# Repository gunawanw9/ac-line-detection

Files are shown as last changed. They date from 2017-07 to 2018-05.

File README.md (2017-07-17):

# [AC mains/ Zero Crossing Detection Module](https://shop.edwinrobotics.com/sensors/960-ac-mains-zero-crossing-detection-module.html) #

AC Mains Zero Crossing Detection PCB.JPG

The AC mains/ Zero Crossing Detection Module from Edwin Robotics is an optically isolated AC line-to-logic interface device. The AC line voltage is monitored by a rectifier and an optocoupler, which provides isolation between High Voltage (HV) and Low Voltage (LV) Side. An active AC power line drives the output gate of the optocoupler to a logic low condition and in the absence of an AC line the output remains HIGH. The board is designed solely for the use as an AC line monitor. By default the output of the optocoupler is connected to a 2.2uF capacitor to provide TTL output, in the event that zero crossing is required, a jumper trace on the back of the PCB will need to be cut. Check the hookup guide for more information. The board has an on board pull-up resistors for uses with microcontrollers with weak pull-up. 

**FEATURES:**

* AC mains & Zero Crossing detection.
* On board pull-up
* High voltage isolation between input and output.
* Logic level compatibility

**SPECIFICATION:**

* Input Voltage Range: 110-300 V AC
* Max. Output Voltage Range: 5V
* Logic Interface: VCC, GND, Signal
* Dimensions: 20x20mm

**DOCUMENTS:**

[Hookup Guide](http://learn.edwinrobotics.com/230v110v-ac-mains-detection-using-arduino-raspberry-pi-and-esp8266-thing/)

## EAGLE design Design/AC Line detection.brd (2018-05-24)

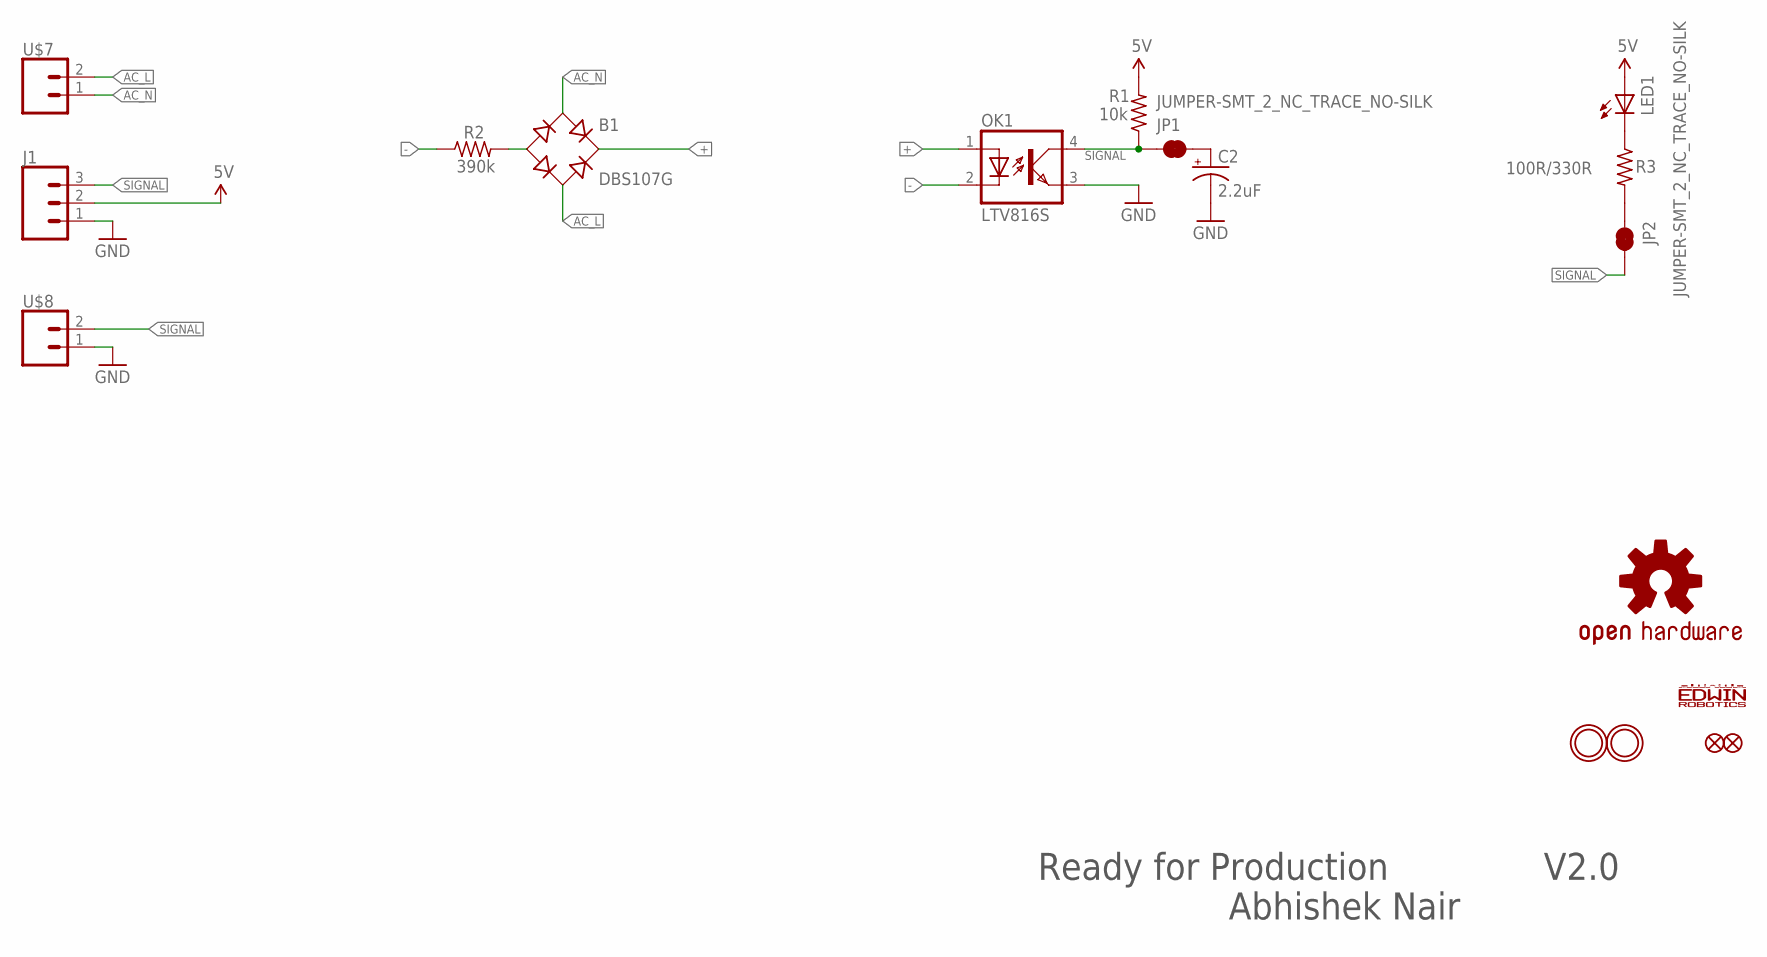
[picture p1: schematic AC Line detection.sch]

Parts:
B1: DBS107G; DBS
C2: 2.2uF; CAPACITOR-2.2UF_4X5MM_JENNY
FID1, FID2: FIDUCIAL""; FIDUCIAL_1MM
J1: CONN_03; 1X03
JP1, JP2: JUMPER-SMT_2_NC_TRACE_NO-SILK; SMT-JUMPER_2_NC_TRACE_NO-SILK
LED1: LED_TH/SMDCHIPLED_0603; CHIPLED_0603
LOGO1: OSHW-LOGOMINI; OSHW-LOGO-MINI
OK1: LTV816S; DIL4-SMD
R1: 10k; R0603
R2: 390k; R0603
R3: 100R/330R; R0603
U$1: LOGO-9.5MMX4.5MM
U$5, U$6: MOUNTINGHOLE3.0THIN; MOUNTINGHOLE_3.0_PLATEDTHIN
U$7, U$8: SCREW_TERMINALS-2P-5MM; W237-102

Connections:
5V: J1.2, LED1.A, R1.2
+: B1.+, OK1.1 (A)
-: OK1.2 (C), R2.1
AC_L: B1.AC2, U$7.2
AC_N: B1.AC1, U$7.1
GND: C2.-, J1.1, OK1.3 (EMIT), U$8.1
unnamed: B1.-, R2.2
unnamed: C2.+, JP1.2
unnamed: LED1.C, R3.1
unnamed: JP2.1, R3.2
SIGNAL: J1.3, JP1.1, JP2.2, OK1.4 (COL), R1.1, U$8.2

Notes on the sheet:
Ready for Production
V2.0
Abhishek Nair

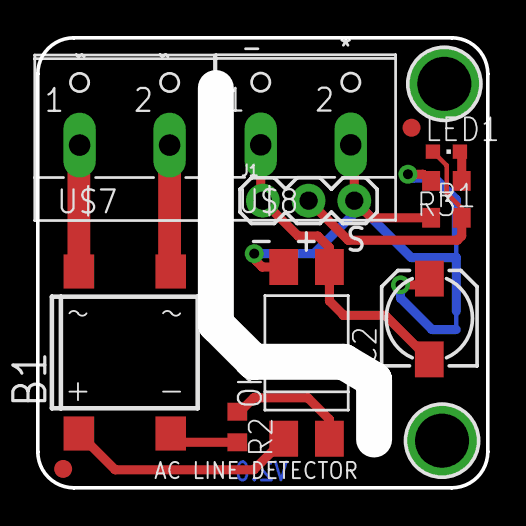
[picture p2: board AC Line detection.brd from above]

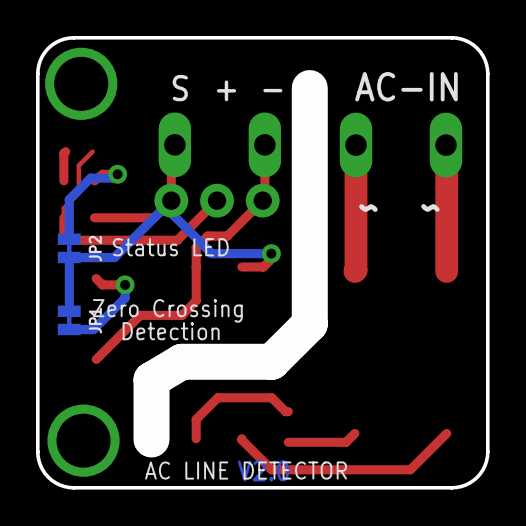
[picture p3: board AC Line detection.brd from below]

Board: 2 copper layers, 25.0 x 25.0 mm, 18 parts (4 on the bottom side), 11 nets.

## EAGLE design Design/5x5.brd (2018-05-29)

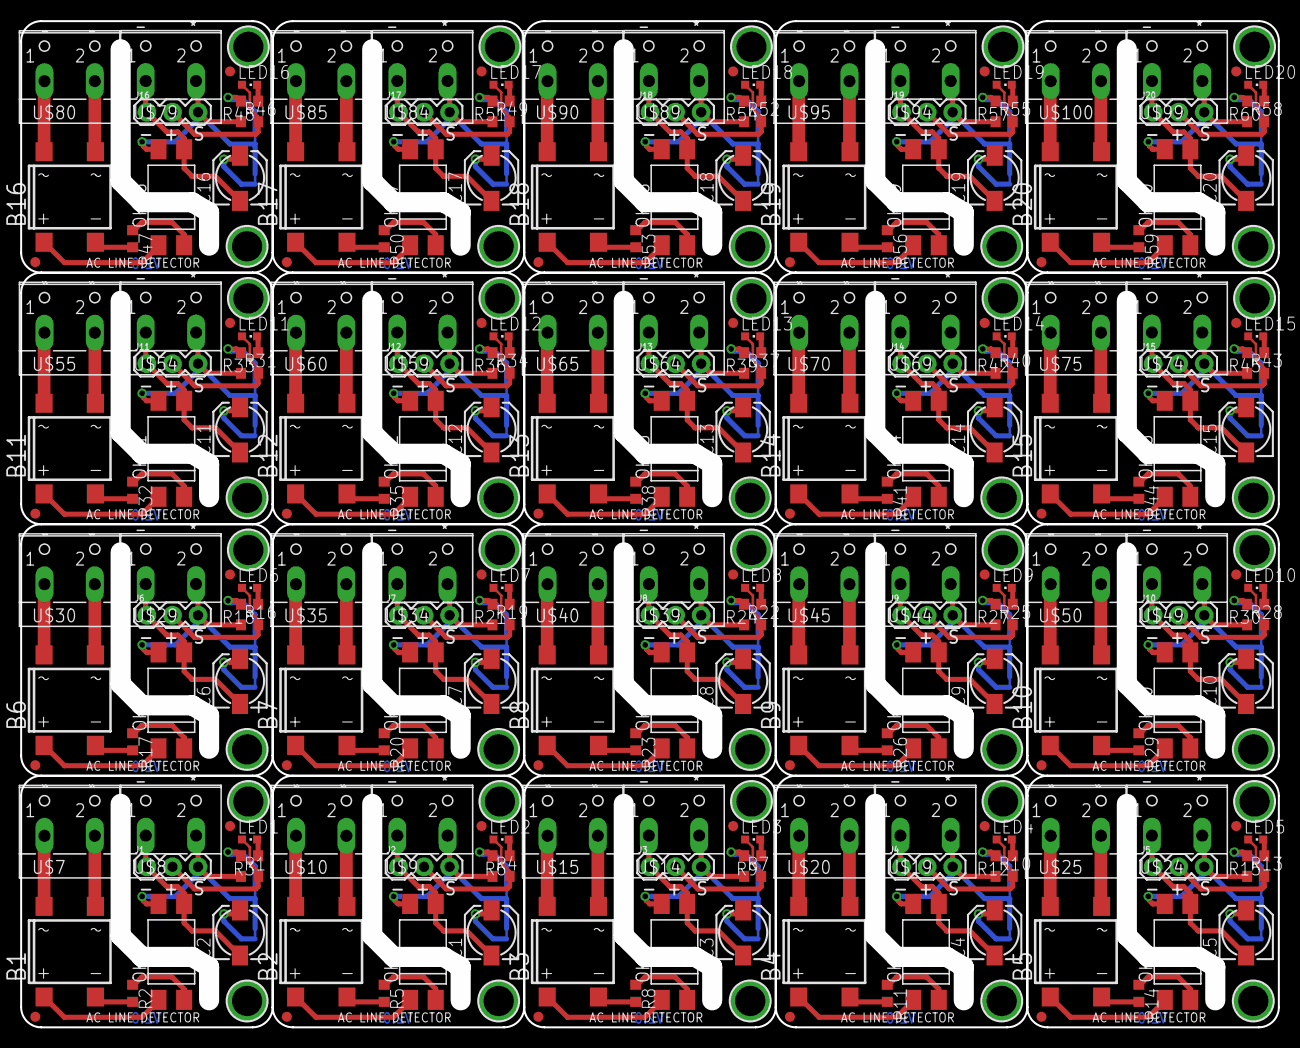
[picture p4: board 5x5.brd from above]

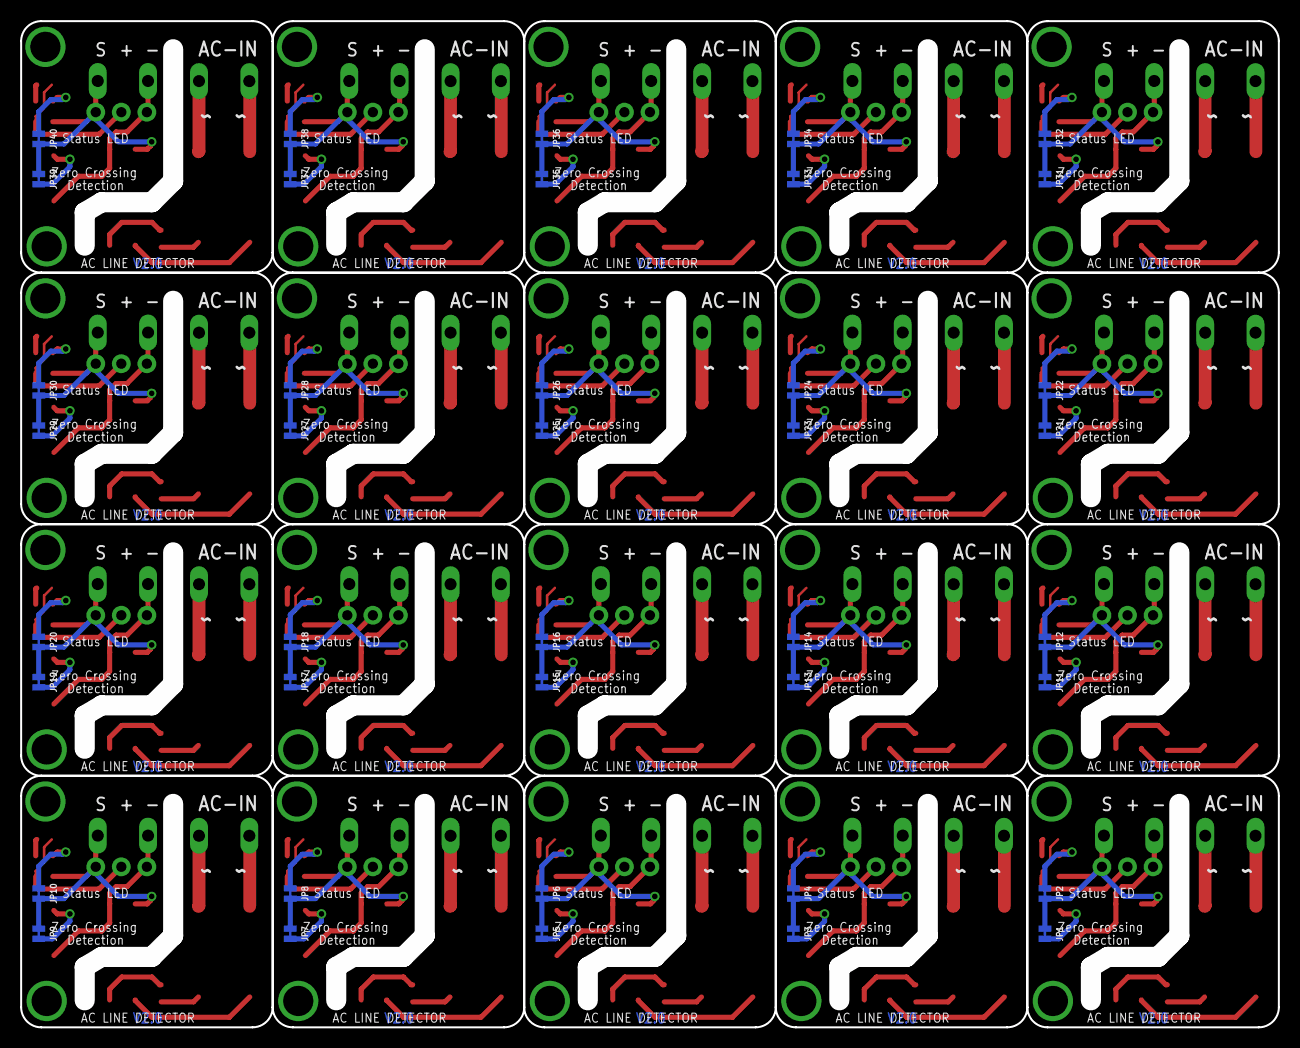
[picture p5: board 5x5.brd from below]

Board: 2 copper layers, 125.0 x 100.0 mm, 360 parts (80 on the bottom side), 220 nets.

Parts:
B1, B2, B3, B4, B5, B6, B7, B8, B9, B10, B11, B12, B13, B14, B15, B16, B17, B18, B19, B20: DBS107G; DBS
C1, C2, C3, C4, C5, C6, C7, C8, C9, C10, C11, C12, C13, C14, C15, C16, C17, C18, C19, C20: 2.2uF; CAPACITOR-2.2UF_4X5MM_JENNY
FID1, FID2, FID3, FID4, FID5, FID6, FID7, FID8, FID9, FID10, FID11, FID12, FID13, FID14, FID15, FID16, FID17, FID18, FID19, FID20, FID21, FID22, FID23, FID24, FID25, FID26, FID27, FID28, FID29, FID30, FID31, FID32, FID33, FID34, FID35, FID36, FID37, FID38, FID39, FID40: FIDUCIAL""; FIDUCIAL_1MM
J1, J2, J3, J4, J5, J6, J7, J8, J9, J10, J11, J12, J13, J14, J15, J16, J17, J18, J19, J20: 1X03
JP1, JP2, JP3, JP4, JP5, JP6, JP7, JP8, JP9, JP10, JP11, JP12, JP13, JP14, JP15, JP16, JP17, JP18, JP19, JP20, JP21, JP22, JP23, JP24, JP25, JP26, JP27, JP28, JP29, JP30, JP31, JP32, JP33, JP34, JP35, JP36, JP37, JP38, JP39, JP40: JUMPER-SMT_2_NC_TRACE_NO-SILK; SMT-JUMPER_2_NC_TRACE_NO-SILK
LED1, LED2, LED3, LED4, LED5, LED6, LED7, LED8, LED9, LED10, LED11, LED12, LED13, LED14, LED15, LED16, LED17, LED18, LED19, LED20: CHIPLED_0603
LOGO1, LOGO2, LOGO3, LOGO4, LOGO5, LOGO6, LOGO7, LOGO8, LOGO9, LOGO10, LOGO11, LOGO12, LOGO13, LOGO14, LOGO15, LOGO16, LOGO17, LOGO18, LOGO19, LOGO20: OSHW-LOGOMINI; OSHW-LOGO-MINI
OK1, OK2, OK3, OK4, OK5, OK6, OK7, OK8, OK9, OK10, OK11, OK12, OK13, OK14, OK15, OK16, OK17, OK18, OK19, OK20: LTV816S; DIL4-SMD
R1, R4, R7, R10, R13, R16, R19, R22, R25, R28, R31, R34, R37, R40, R43, R46, R49, R52, R55, R58: 10k; R0603
R2, R5, R8, R11, R14, R17, R20, R23, R26, R29, R32, R35, R38, R41, R44, R47, R50, R53, R56, R59: 390k; R0603
R3, R6, R9, R12, R15, R18, R21, R24, R27, R30, R33, R36, R39, R42, R45, R48, R51, R54, R57, R60: 100R/330R; R0603
U$1, U$2, U$11, U$16, U$21, U$26, U$31, U$36, U$41, U$46, U$51, U$56, U$61, U$66, U$71, U$76, U$81, U$86, U$91, U$96: LOGO-9.5MMX4.5MM
U$3, U$4, U$5, U$6, U$12, U$13, U$17, U$18, U$22, U$23, U$27, U$28, U$32, U$33, U$37, U$38, U$42, U$43, U$47, U$48, U$52, U$53, U$57, U$58, U$62, U$63, U$67, U$68, U$72, U$73, U$77, U$78, U$82, U$83, U$87, U$88, U$92, U$93, U$97, U$98: MOUNTINGHOLE3.0THIN; MOUNTINGHOLE_3.0_PLATEDTHIN
U$7, U$8, U$9, U$10, U$14, U$15, U$19, U$20, U$24, U$25, U$29, U$30, U$34, U$35, U$39, U$40, U$44, U$45, U$49, U$50, U$54, U$55, U$59, U$60, U$64, U$65, U$69, U$70, U$74, U$75, U$79, U$80, U$84, U$85, U$89, U$90, U$94, U$95, U$99, U$100: SCREW_TERMINALS-2P-5MM; W237-102

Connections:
5V: J1.2, LED1.A, R1.2
5V1: J2.2, LED2.A, R4.2
5V2: J3.2, LED3.A, R7.2
5V3: J4.2, LED4.A, R10.2
5V4: J5.2, LED5.A, R13.2
5V5: J6.2, LED6.A, R16.2
5V6: J7.2, LED7.A, R19.2
5V7: J8.2, LED8.A, R22.2
5V8: J9.2, LED9.A, R25.2
5V9: J10.2, LED10.A, R28.2
5V10: J11.2, LED11.A, R31.2
5V11: J12.2, LED12.A, R34.2
5V12: J13.2, LED13.A, R37.2
5V13: J14.2, LED14.A, R40.2
5V14: J15.2, LED15.A, R43.2
5V15: J16.2, LED16.A, R46.2
5V16: J17.2, LED17.A, R49.2
5V17: J18.2, LED18.A, R52.2
5V18: J19.2, LED19.A, R55.2
5V19: J20.2, LED20.A, R58.2
+: B1.+, OK1.1
+1: B2.+, OK2.1
+2: B3.+, OK3.1
+3: B4.+, OK4.1
+4: B5.+, OK5.1
+5: B6.+, OK6.1
+6: B7.+, OK7.1
+7: B8.+, OK8.1
+8: B9.+, OK9.1
+9: B10.+, OK10.1
+10: B11.+, OK11.1
+11: B12.+, OK12.1
+12: B13.+, OK13.1
+13: B14.+, OK14.1
+14: B15.+, OK15.1
+15: B16.+, OK16.1
+16: B17.+, OK17.1
+17: B18.+, OK18.1
+18: B19.+, OK19.1
+19: B20.+, OK20.1
-: OK1.2, R2.1
-1: OK2.2, R5.1
-2: OK3.2, R8.1
-3: OK4.2, R11.1
-4: OK5.2, R14.1
-5: OK6.2, R17.1
-6: OK7.2, R20.1
-7: OK8.2, R23.1
-8: OK9.2, R26.1
-9: OK10.2, R29.1
-10: OK11.2, R32.1
-11: OK12.2, R35.1
-12: OK13.2, R38.1
-13: OK14.2, R41.1
-14: OK15.2, R44.1
-15: OK16.2, R47.1
-16: OK17.2, R50.1
-17: OK18.2, R53.1
-18: OK19.2, R56.1
-19: OK20.2, R59.1
AC_L: B1.AC2, U$7.2
AC_L1: B2.AC2, U$10.2
AC_L2: B3.AC2, U$15.2
AC_L3: B4.AC2, U$20.2
AC_L4: B5.AC2, U$25.2
AC_L5: B6.AC2, U$30.2
AC_L6: B7.AC2, U$35.2
AC_L7: B8.AC2, U$40.2
AC_L8: B9.AC2, U$45.2
AC_L9: B10.AC2, U$50.2
AC_L10: B11.AC2, U$55.2
AC_L11: B12.AC2, U$60.2
AC_L12: B13.AC2, U$65.2
AC_L13: B14.AC2, U$70.2
AC_L14: B15.AC2, U$75.2
AC_L15: B16.AC2, U$80.2
AC_L16: B17.AC2, U$85.2
AC_L17: B18.AC2, U$90.2
AC_L18: B19.AC2, U$95.2
AC_L19: B20.AC2, U$100.2
AC_N: B1.AC1, U$7.1
AC_N1: B2.AC1, U$10.1
AC_N2: B3.AC1, U$15.1
AC_N3: B4.AC1, U$20.1
AC_N4: B5.AC1, U$25.1
AC_N5: B6.AC1, U$30.1
AC_N6: B7.AC1, U$35.1
AC_N7: B8.AC1, U$40.1
AC_N8: B9.AC1, U$45.1
AC_N9: B10.AC1, U$50.1
AC_N10: B11.AC1, U$55.1
AC_N11: B12.AC1, U$60.1
AC_N12: B13.AC1, U$65.1
AC_N13: B14.AC1, U$70.1
AC_N14: B15.AC1, U$75.1
AC_N15: B16.AC1, U$80.1
AC_N16: B17.AC1, U$85.1
AC_N17: B18.AC1, U$90.1
AC_N18: B19.AC1, U$95.1
AC_N19: B20.AC1, U$100.1
GND: C2.-, J1.1, OK1.3, U$8.1
GND1: C1.-, J2.1, OK2.3, U$9.1
GND2: C3.-, J3.1, OK3.3, U$14.1
GND3: C4.-, J4.1, OK4.3, U$19.1
GND4: C5.-, J5.1, OK5.3, U$24.1
GND5: C6.-, J6.1, OK6.3, U$29.1
GND6: C7.-, J7.1, OK7.3, U$34.1
GND7: C8.-, J8.1, OK8.3, U$39.1
GND8: C9.-, J9.1, OK9.3, U$44.1
GND9: C10.-, J10.1, OK10.3, U$49.1
GND10: C11.-, J11.1, OK11.3, U$54.1
GND11: C12.-, J12.1, OK12.3, U$59.1
GND12: C13.-, J13.1, OK13.3, U$64.1
GND13: C14.-, J14.1, OK14.3, U$69.1
GND14: C15.-, J15.1, OK15.3, U$74.1
GND15: C16.-, J16.1, OK16.3, U$79.1
GND16: C17.-, J17.1, OK17.3, U$84.1
GND17: C18.-, J18.1, OK18.3, U$89.1
GND18: C19.-, J19.1, OK19.3, U$94.1
GND19: C20.-, J20.1, OK20.3, U$99.1
unnamed: B1.-, R2.2
unnamed: C2.+, JP1.2
unnamed: LED1.C, R3.1
unnamed: JP2.1, R3.2
unnamed: B2.-, R5.2
unnamed: C1.+, JP3.2
unnamed: JP4.1, R6.2
unnamed: LED2.C, R6.1
unnamed: B3.-, R8.2
unnamed: C3.+, JP5.2
unnamed: JP6.1, R9.2
unnamed: LED3.C, R9.1
unnamed: B4.-, R11.2
unnamed: C4.+, JP7.2
unnamed: JP8.1, R12.2
unnamed: LED4.C, R12.1
unnamed: B5.-, R14.2
unnamed: C5.+, JP9.2
unnamed: JP10.1, R15.2
unnamed: LED5.C, R15.1
unnamed: B6.-, R17.2
unnamed: C6.+, JP11.2
unnamed: JP12.1, R18.2
unnamed: LED6.C, R18.1
unnamed: B7.-, R20.2
unnamed: C7.+, JP13.2
unnamed: JP14.1, R21.2
unnamed: LED7.C, R21.1
unnamed: B8.-, R23.2
unnamed: C8.+, JP15.2
unnamed: JP16.1, R24.2
unnamed: LED8.C, R24.1
unnamed: B9.-, R26.2
unnamed: C9.+, JP17.2
unnamed: JP18.1, R27.2
unnamed: LED9.C, R27.1
unnamed: B10.-, R29.2
unnamed: C10.+, JP19.2
unnamed: JP20.1, R30.2
unnamed: LED10.C, R30.1
unnamed: B11.-, R32.2
unnamed: C11.+, JP21.2
unnamed: JP22.1, R33.2
unnamed: LED11.C, R33.1
unnamed: B12.-, R35.2
unnamed: C12.+, JP23.2
unnamed: JP24.1, R36.2
unnamed: LED12.C, R36.1
unnamed: B13.-, R38.2
unnamed: C13.+, JP25.2
unnamed: JP26.1, R39.2
unnamed: LED13.C, R39.1
unnamed: B14.-, R41.2
unnamed: C14.+, JP27.2
unnamed: JP28.1, R42.2
unnamed: LED14.C, R42.1
unnamed: B15.-, R44.2
unnamed: C15.+, JP29.2
unnamed: JP30.1, R45.2
unnamed: LED15.C, R45.1
unnamed: B16.-, R47.2
unnamed: C16.+, JP31.2
unnamed: JP32.1, R48.2
unnamed: LED16.C, R48.1
unnamed: B17.-, R50.2
unnamed: C17.+, JP33.2
unnamed: JP34.1, R51.2
unnamed: LED17.C, R51.1
unnamed: B18.-, R53.2
unnamed: C18.+, JP35.2
unnamed: JP36.1, R54.2
unnamed: LED18.C, R54.1
unnamed: B19.-, R56.2
unnamed: C19.+, JP37.2
unnamed: JP38.1, R57.2
unnamed: LED19.C, R57.1
unnamed: B20.-, R59.2
unnamed: C20.+, JP39.2
unnamed: JP40.1, R60.2
unnamed: LED20.C, R60.1
SIGNAL: J1.3, JP1.1, JP2.2, OK1.4, R1.1, U$8.2
SIGNAL1: J2.3, JP3.1, JP4.2, OK2.4, R4.1, U$9.2
SIGNAL2: J3.3, JP5.1, JP6.2, OK3.4, R7.1, U$14.2
SIGNAL3: J4.3, JP7.1, JP8.2, OK4.4, R10.1, U$19.2
SIGNAL4: J5.3, JP9.1, JP10.2, OK5.4, R13.1, U$24.2
SIGNAL5: J6.3, JP11.1, JP12.2, OK6.4, R16.1, U$29.2
SIGNAL6: J7.3, JP13.1, JP14.2, OK7.4, R19.1, U$34.2
SIGNAL7: J8.3, JP15.1, JP16.2, OK8.4, R22.1, U$39.2
SIGNAL8: J9.3, JP17.1, JP18.2, OK9.4, R25.1, U$44.2
SIGNAL9: J10.3, JP19.1, JP20.2, OK10.4, R28.1, U$49.2
SIGNAL10: J11.3, JP21.1, JP22.2, OK11.4, R31.1, U$54.2
SIGNAL11: J12.3, JP23.1, JP24.2, OK12.4, R34.1, U$59.2
SIGNAL12: J13.3, JP25.1, JP26.2, OK13.4, R37.1, U$64.2
SIGNAL13: J14.3, JP27.1, JP28.2, OK14.4, R40.1, U$69.2
SIGNAL14: J15.3, JP29.1, JP30.2, OK15.4, R43.1, U$74.2
SIGNAL15: J16.3, JP31.1, JP32.2, OK16.4, R46.1, U$79.2
SIGNAL16: J17.3, JP33.1, JP34.2, OK17.4, R49.1, U$84.2
SIGNAL17: J18.3, JP35.1, JP36.2, OK18.4, R52.1, U$89.2
SIGNAL18: J19.3, JP37.1, JP38.2, OK19.4, R55.1, U$94.2
SIGNAL19: J20.3, JP39.1, JP40.2, OK20.4, R58.1, U$99.2

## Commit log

2017-06-08 Version 1.0
    Tested Circuit and Design
    [AC Line detection.brd, AC Line detection.sch]
2017-06-12 version 1.0
    * Added production files
    [AC Line detection.brd]
2017-06-13 Version 1.0
    * updated schematics: Added electrolytic capacitor on board
    * Updated board: increased dimesnions and new routing
    [AC Line detection.brd, AC Line detection.sch]
2017-06-13 version 1.0 update:
    * Updated Capacitor Pad Size
    [AC Line detection.brd, AC Line detection.sch]
2017-07-09 *Removed production files* *Added Licesence and readme file*
    [AC Line detection.sch]
2018-03-29 Version 2.0:
    Major Changes:
    *Updated Design FIles
    * Updated the board Size
    * Added mounting Holes
    * Added Debug LED and enable/Disbale Jumper
    * Replaced Screw terminal with KF126
    [AC Line detection.brd, AC Line detection.sch]
2018-05-24 Version 2.0: Added Gerber Files
    [AC Line detection.brd, AC Line detection.sch]
